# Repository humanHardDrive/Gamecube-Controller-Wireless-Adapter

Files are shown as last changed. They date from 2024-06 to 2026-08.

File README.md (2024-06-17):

# GameCube Wireless Controller Hub
The GameCube Wireless Controller hub allows 4 GameCube controllers to be made wireless to any GameCube controller interface. The hub functions in two halves, one to connect to the controllers, and one to connect to the console. Both halves are based on the RP2040 microcontroller and the NRF24l01 transceiver and share the same source code.

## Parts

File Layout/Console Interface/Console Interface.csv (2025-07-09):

# | Reference | Qty | Value | Footprint | DNP
1 | C1, C7, C9 | 3 | 2u2 | Capacitor_SMD:C_0603_1608Metric
2 | C2, C5, C6, C8, C10, C11, C12, C13, C14 | 9 | 100n | Capacitor_SMD:C_0603_1608Metric
3 | C3, C4 | 2 | 15p | Capacitor_SMD:C_0603_1608Metric
4 | C15, C16, C19, C20 | 4 | C | Capacitor_SMD:C_0603_1608Metric
5 | D1, D4, D5, D6, D7, D8, D9 | 7 | LED | LED_SMD:LED_0603_1608Metric
6 | D2, D3 | 2 | D_Schottky | Diode_SMD:D_0805_2012Metric
7 | H1, H2, H3, H4 | 4 | MountingHole | MountingHole:MountingHole_2.2mm_M2
8 | J1 | 1 | USB_C_Receptacle_USB2.0 | Connector_USB:USB_C_Receptacle_GCT_USB4105-xx-A_16P_TopMnt_Horizontal
9 | J2, J3, J4, J6 | 4 | Conn_01x04_Socket | Connector_Molex:Molex_Pico-EZmate_78171-0005_1x05-1MP_P1.20mm_Vertical
10 | Q1 | 1 | AO3401A | Package_TO_SOT_SMD:SOT-23
11 | R1 | 1 | 1K | Resistor_SMD:R_0603_1608Metric
12 | R2, R3 | 2 | 27 | Resistor_SMD:R_0603_1608Metric
13 | R4, R5 | 2 | 5K1 | Resistor_SMD:R_0603_1608Metric
14 | R6, R8, R11, R12, R13, R16, R17 | 7 | 100 | Resistor_SMD:R_0603_1608Metric
15 | R7 | 1 | 10K | Resistor_SMD:R_0603_1608Metric
16 | SW1 | 1 | SW_BOOT | Button_Switch_SMD:SW_SPST_TL3342
17 | SW3 | 1 | SW_PAIR | Button_Switch_SMD:SW_SPST_B3U-3000P
18 | U1 | 1 | W25Q32JVSS | Package_SO:SOIC-8_5.23x5.23mm_P1.27mm
19 | U2 | 1 | RP2040 | Package_DFN_QFN:QFN-56-1EP_7x7mm_P0.4mm_EP3.2x3.2mm
20 | U3 | 1 | ~ | GTS24:GTS24-SMD
21 | U4, U5 | 2 | MIC5504-3.3YM5 | Package_TO_SOT_SMD:SOT-23-5
22 | Y1 | 1 | Crystal_GND24 | Crystal:Crystal_SMD_Abracon_ABM8G-4Pin_3.2x2.5mm

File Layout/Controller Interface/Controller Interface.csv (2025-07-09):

# | Reference | Qty | Value | Footprint | DNP
1 | C1, C12, C13, C14, C16, C17, C18, C19, C20 | 9 | 100n | Capacitor_SMD:C_0603_1608Metric
2 | C2, C11, C15 | 3 | 2u2 | Capacitor_SMD:C_0603_1608Metric
3 | C3, C4 | 2 | 15p | Capacitor_SMD:C_0603_1608Metric
4 | C5, C6 | 2 | 1u | Capacitor_SMD:C_0603_1608Metric
5 | C7, C8 | 2 | 1uF | Capacitor_SMD:C_0603_1608Metric
6 | C9 | 1 | 4.7uF | Capacitor_SMD:C_0603_1608Metric
7 | C10 | 1 | 22uF | Capacitor_SMD:C_0603_1608Metric
8 | D2, D3 | 2 | D_Schottky | Diode_SMD:D_0805_2012Metric
9 | J1 | 1 | USB_C_Receptacle_USB2.0 | Connector_USB:USB_C_Receptacle_GCT_USB4105-xx-A_16P_TopMnt_Horizontal
10 | J2 | 1 | Controller 2 | GameCube Controllers:Gamecube Controller Socket
11 | J3 | 1 | Controller 3 | GameCube Controllers:Gamecube Controller Socket
12 | J4 | 1 | Controller 4 | GameCube Controllers:Gamecube Controller Socket
13 | J5 | 1 | Conn_01x08_Socket | Connector_PinSocket_1.00mm:PinSocket_2x04_P1.00mm_Vertical_SMD
14 | J6 | 1 | Conn_01x02_Pin | Connector_JST:JST_PH_S2B-PH-SM4-TB_1x02-1MP_P2.00mm_Horizontal
15 | J7 | 1 | Controller 1 | GameCube Controllers:Gamecube Controller Socket
16 | L2 | 1 | 2.2uH | Inductor_SMD:L_0805_2012Metric
17 | Q1, Q2, Q3 | 3 | AO3401A | Package_TO_SOT_SMD:SOT-23
18 | R1, R2, R3, R13, R15 | 5 | 1K | Resistor_SMD:R_0603_1608Metric
19 | R5, R12 | 2 | 10k | Resistor_SMD:R_0603_1608Metric
20 | R6, R7 | 2 | 27 | Resistor_SMD:R_0603_1608Metric
21 | R8, R9 | 2 | 5K1 | Resistor_SMD:R_0603_1608Metric
22 | R10 | 1 | 2K | Resistor_SMD:R_0603_1608Metric
23 | R11 | 1 | 10K | Resistor_SMD:R_0603_1608Metric
24 | SW1 | 1 | PWR | Button_Switch_SMD:Panasonic_EVQPUK_EVQPUB
25 | SW3 | 1 | SW_PAIR | Button_Switch_SMD:Panasonic_EVQPUK_EVQPUB
26 | SW4 | 1 | SW_BOOT | Button_Switch_SMD:SW_SPST_TL3342
27 | U1 | 1 | W25Q32JVSS | Package_SO:SOIC-8_5.23x5.23mm_P1.27mm
28 | U2 | 1 | RP2040 | Package_DFN_QFN:QFN-56-1EP_7x7mm_P0.4mm_EP3.2x3.2mm
29 | U3 | 1 | ~ | GTS24:GTS24-SMD
30 | U4 | 1 | MCP73812T-420I-OT | Package_TO_SOT_SMD:SOT-23-5
31 | U5 | 1 | TPS613223ADBV | Package_TO_SOT_SMD:SOT-23-5
32 | U7 | 1 | MIC5504-3.3YM5 | Package_TO_SOT_SMD:SOT-23-5
33 | Y2 | 1 | Crystal_GND24 | Crystal:Crystal_SMD_Abracon_ABM8G-4Pin_3.2x2.5mm

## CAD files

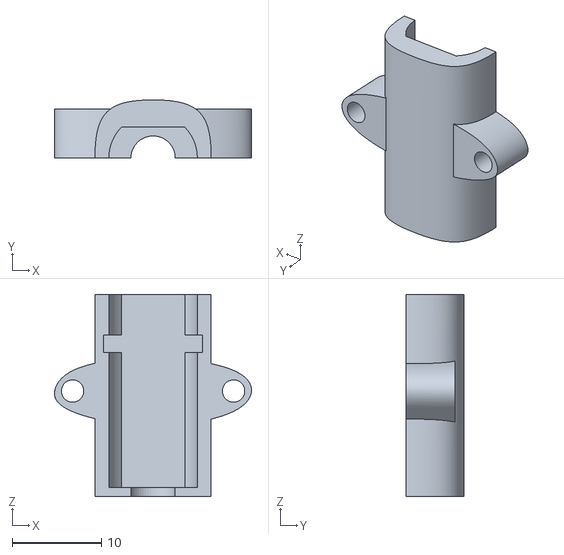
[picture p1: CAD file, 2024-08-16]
Enclosures/Console Interface/Controller Plug Clamp Top.stl
22.0 x 6.50 x 22.6

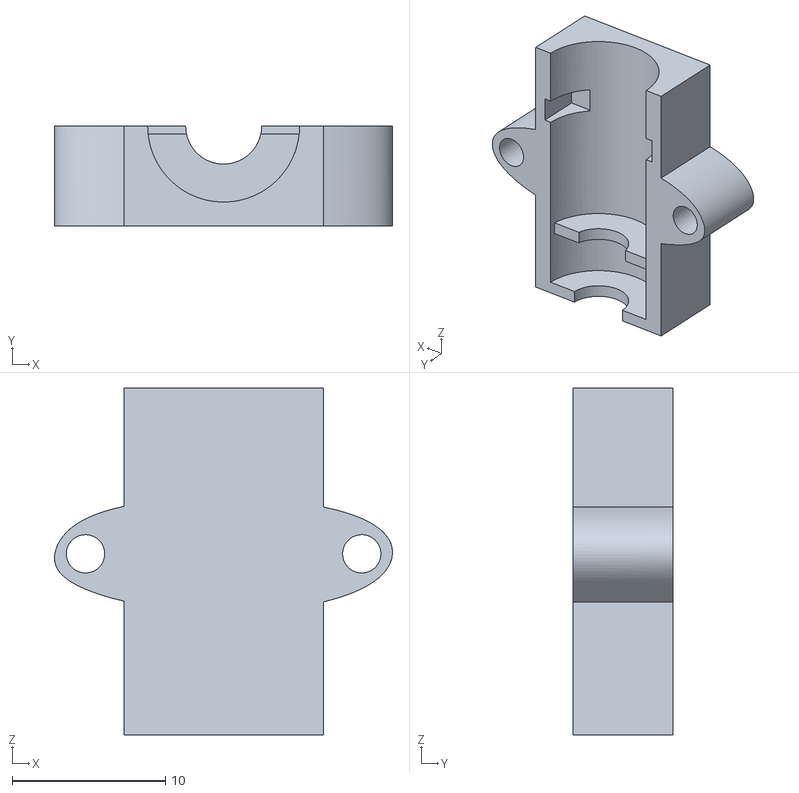
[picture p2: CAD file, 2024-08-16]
Enclosures/Console Interface/Controller Plug Clamp Bottom.stl
22.0 x 6.50 x 22.6

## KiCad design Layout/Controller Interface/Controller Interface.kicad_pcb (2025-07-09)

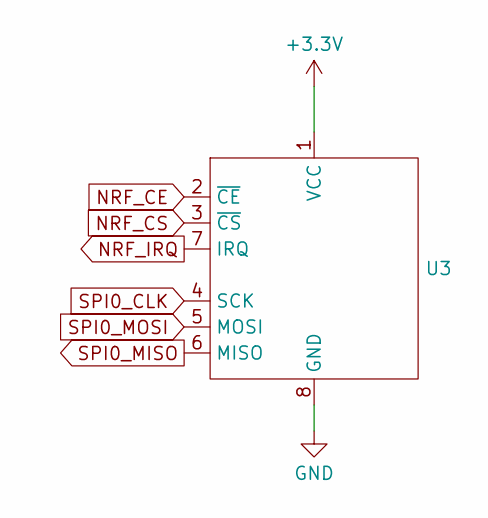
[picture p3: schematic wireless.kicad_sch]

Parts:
U3: GTS24-SMD

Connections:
+3.3V: U3.1 (VCC); also elsewhere on the board
GND: U3.8 (GND); also elsewhere on the board
NRF_CE: U3.2 (~CE); also elsewhere on the board
NRF_CS: U3.3 (~CS); also elsewhere on the board
NRF_IRQ: U3.7 (IRQ); also elsewhere on the board
SPI0_CLK: U3.4 (SCK); also elsewhere on the board
SPI0_MISO: U3.6 (MISO); also elsewhere on the board
SPI0_MOSI: U3.5 (MOSI); also elsewhere on the board

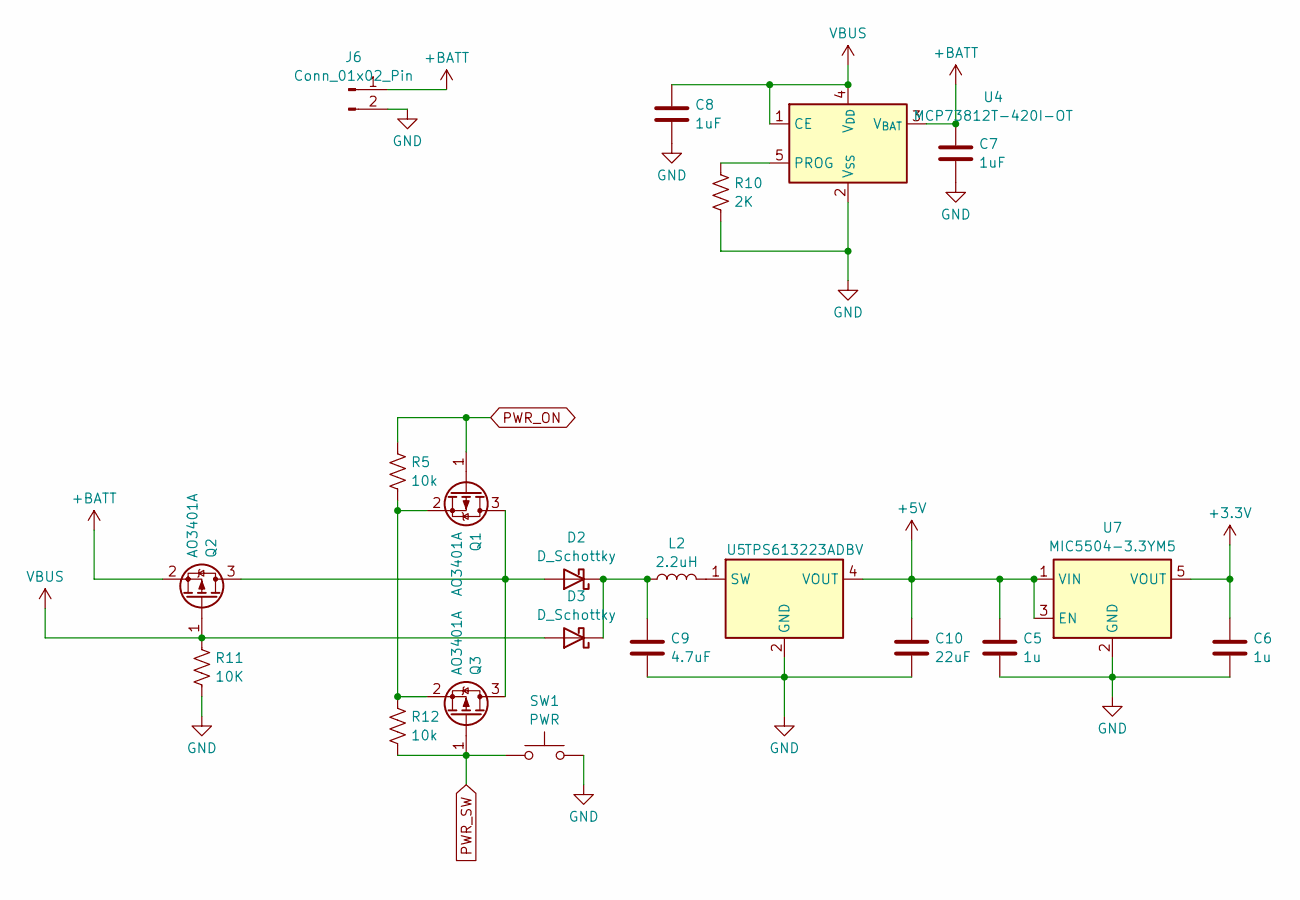
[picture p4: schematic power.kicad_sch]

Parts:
C5, C6: 1u; C_0603_1608Metric
C7, C8: 1uF; C_0603_1608Metric
C9: 4.7uF; C_0603_1608Metric
C10: 22uF; C_0603_1608Metric
D2, D3: D_Schottky; D_0805_2012Metric
J6: Conn_01x02_Pin; JST_PH_S2B-PH-SM4-TB_1x02-1MP_P2.00mm_Horizontal
L2: 2.2uH; L_0805_2012Metric
Q1, Q2, Q3: AO3401A; SOT-23
R5, R12: 10k; R_0603_1608Metric
R10: 2K; R_0603_1608Metric
R11: 10K; R_0603_1608Metric
SW1: PWR; Panasonic_EVQPUK_EVQPUB
U4: MCP73812T-420I-OT; SOT-23-5
U5: TPS613223ADBV; SOT-23-5
U7: MIC5504-3.3YM5; SOT-23-5

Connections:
+3.3V: C6.1, U7.5 (VOUT); also elsewhere on the board
+5V: C5.1, C10.1, U5.4 (VOUT), U7.1 (VIN), U7.3 (EN); also elsewhere on the board
+BATT: C7.1, J6.1, Q2.2 (S), U4.3 (V_{BAT})
GND: C5.2, C6.2, C7.2, C8.2, C9.2, C10.2, J6.2, R10.2, R11.1, SW1.2, U4.2 (V_{SS}), U5.2 (GND), U7.2 (GND); also elsewhere on the board
unnamed: D2.2 (A), Q1.3 (D), Q2.3 (D), Q3.3 (D)
unnamed: C9.1, D2.1 (K), D3.1 (K), L2.1
unnamed: Q1.2 (S), Q3.2 (S), R5.2, R12.1
unnamed: R10.1, U4.5 (PROG)
unnamed: L2.2, U5.1 (SW)
PWR_ON: Q1.1 (G), R5.1; also elsewhere on the board
PWR_SW: Q3.1 (G), R12.2, SW1.1; also elsewhere on the board
VBUS: C8.1, D3.2 (A), Q2.1 (G), R11.2, U4.1 (CE), U4.4 (V_{DD}); also elsewhere on the board

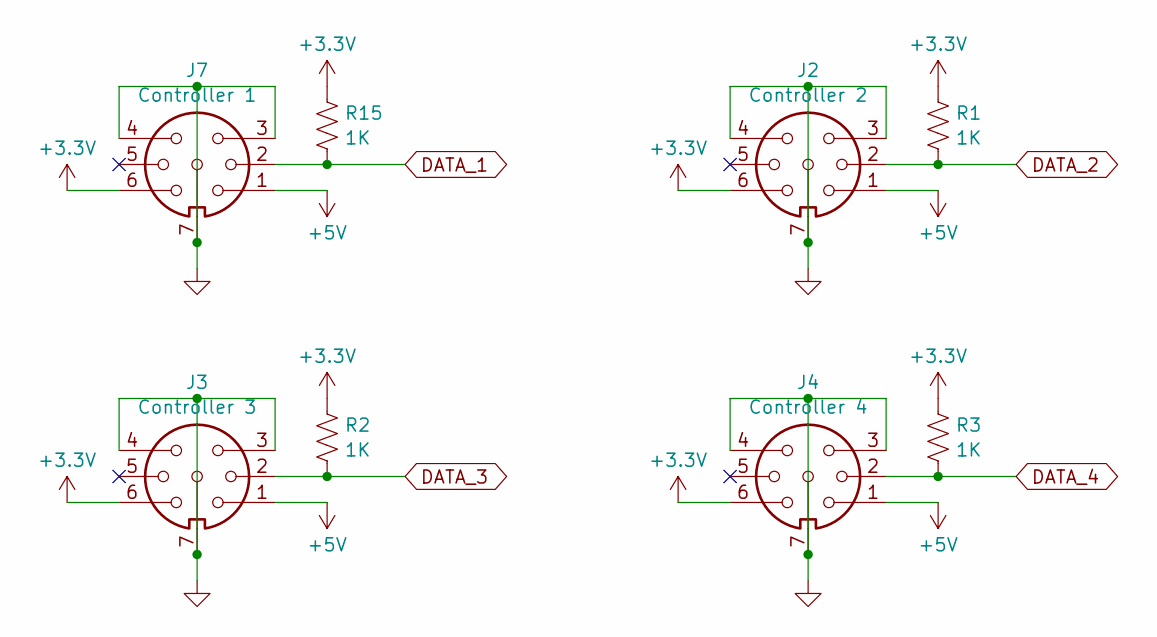
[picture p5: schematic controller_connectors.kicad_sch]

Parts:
J2: Controller 2; Gamecube Controller Socket
J3: Controller 3; Gamecube Controller Socket
J4: Controller 4; Gamecube Controller Socket
J7: Controller 1; Gamecube Controller Socket
R1, R2, R3, R15: 1K; R_0603_1608Metric

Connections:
+3.3V: J2.6, J3.6, J4.6, J7.6, R1.1, R2.1, R3.1, R15.1; also elsewhere on the board
+5V: J2.1, J3.1, J4.1, J7.1; also elsewhere on the board
DATA_1: J7.2, R15.2; also elsewhere on the board
DATA_2: J2.2, R1.2; also elsewhere on the board
DATA_3: J3.2, R2.2; also elsewhere on the board
DATA_4: J4.2, R3.2; also elsewhere on the board
GND: J2.3, J2.4, J2.7, J3.3, J3.4, J3.7, J4.3, J4.4, J4.7, J7.3, J7.4, J7.7; also elsewhere on the board

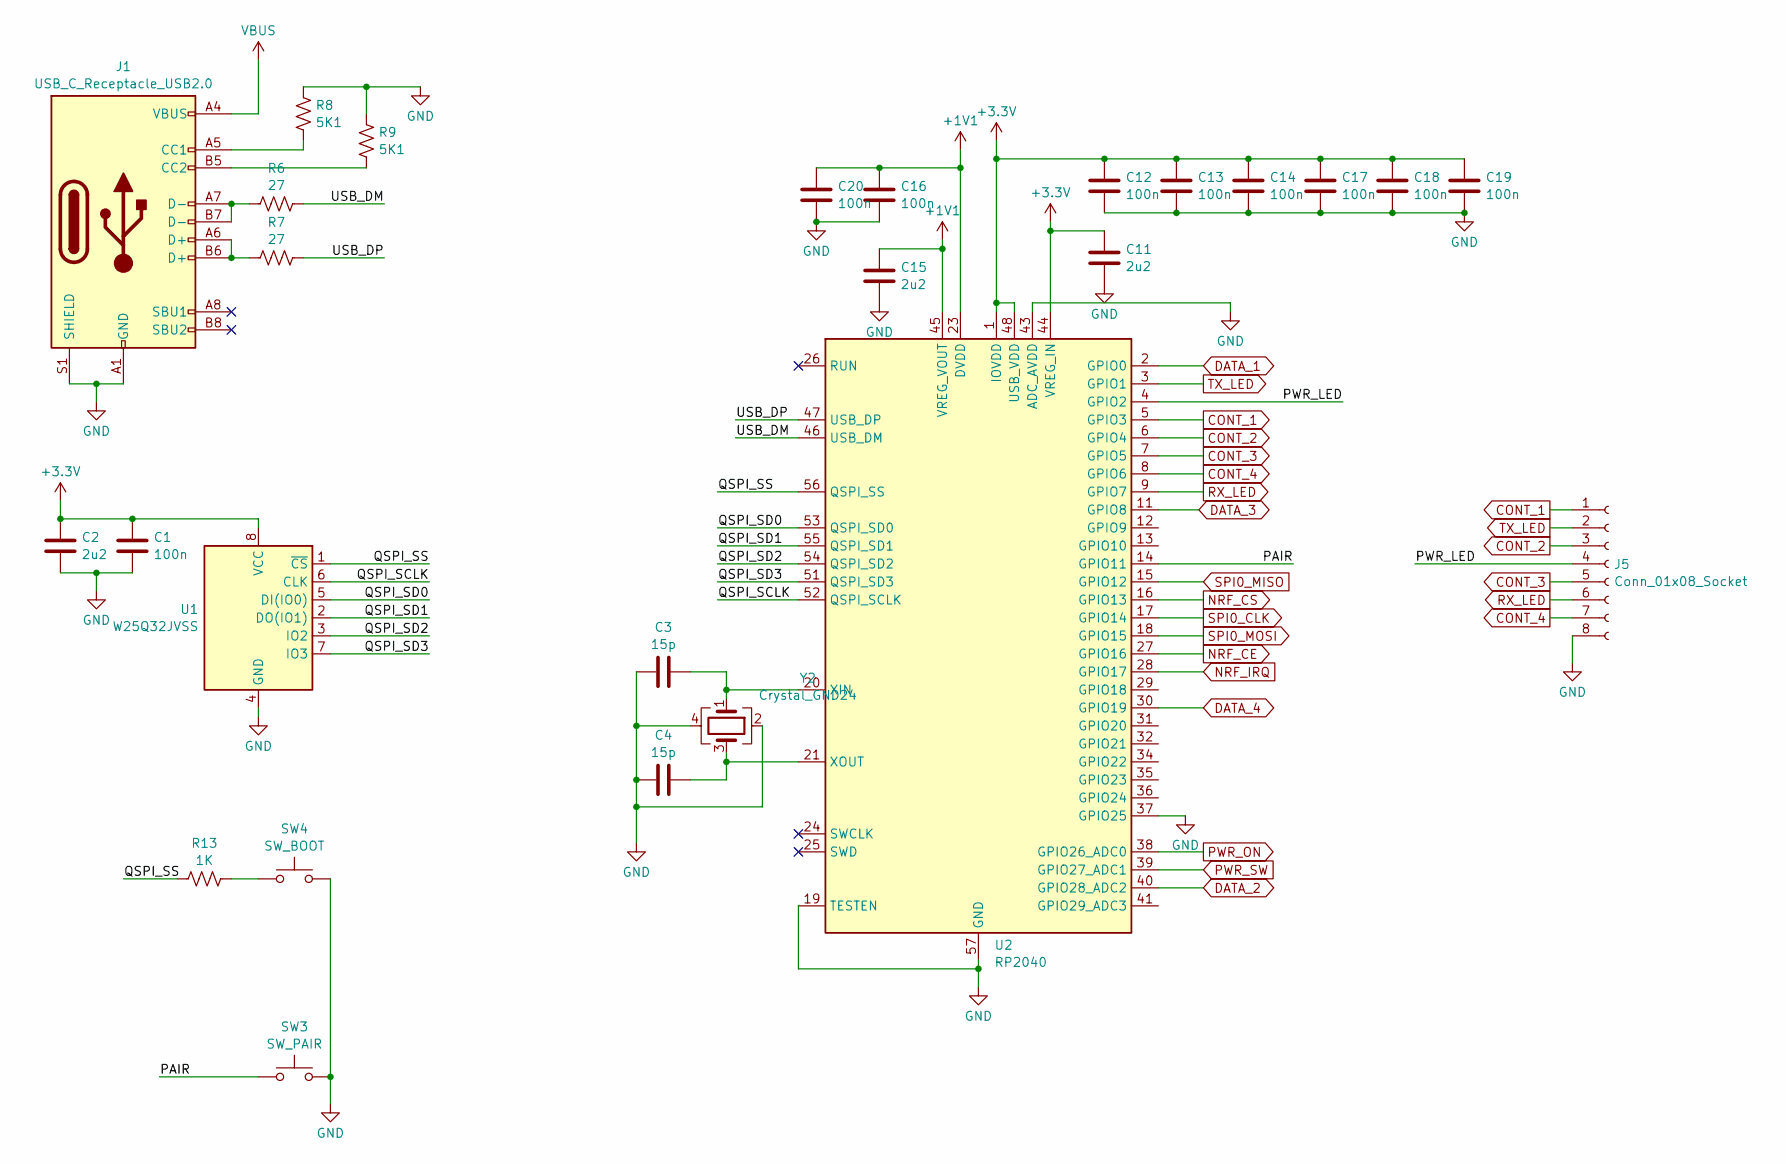
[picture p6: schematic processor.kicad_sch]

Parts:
C1, C12, C13, C14, C16, C17, C18, C19, C20: 100n; C_0603_1608Metric
C2, C11, C15: 2u2; C_0603_1608Metric
C3, C4: 15p; C_0603_1608Metric
J1: USB_C_Receptacle_USB2.0; USB_C_Receptacle_GCT_USB4105-xx-A_16P_TopMnt_Horizontal
J5: Conn_01x08_Socket; PinSocket_2x04_P1.00mm_Vertical_SMD
R6, R7: 27; R_0603_1608Metric
R8, R9: 5K1; R_0603_1608Metric
R13: 1K; R_0603_1608Metric
SW3: SW_PAIR; Panasonic_EVQPUK_EVQPUB
SW4: SW_BOOT; SW_SPST_TL3342
U1: W25Q32JVSS; SOIC-8_5.23x5.23mm_P1.27mm
U2: RP2040; QFN-56-1EP_7x7mm_P0.4mm_EP3.2x3.2mm
Y2: Crystal_GND24; Crystal_SMD_Abracon_ABM8G-4Pin_3.2x2.5mm

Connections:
+1V1: C15.1, C16.1, C20.1, U2.23 (DVDD), U2.45 (VREG_VOUT), U2.50 (DVDD)
+3.3V: C1.1, C2.1, C11.1, C12.1, C13.1, C14.1, C17.1, C18.1, C19.1, U1.8 (VCC), U2.1 (IOVDD), U2.10 (IOVDD), U2.22 (IOVDD), U2.33 (IOVDD), U2.42 (IOVDD), U2.44 (VREG_IN), U2.48 (USB_VDD), U2.49 (IOVDD); also elsewhere on the board
/Processor/PAIR: SW3.1, U2.14 (GPIO11)
/Processor/PWR_LED: J5.4, U2.4 (GPIO2)
/Processor/QSPI_SCLK: U1.6 (CLK), U2.52 (QSPI_SCLK)
/Processor/QSPI_SD0: U1.5 (DI(IO0)), U2.53 (QSPI_SD0)
/Processor/QSPI_SD1: U1.2 (DO(IO1)), U2.55 (QSPI_SD1)
/Processor/QSPI_SD2: U1.3 (IO2), U2.54 (QSPI_SD2)
/Processor/QSPI_SD3: U1.7 (IO3), U2.51 (QSPI_SD3)
/Processor/QSPI_SS: R13.1, U1.1 (~CS), U2.56 (QSPI_SS)
/Processor/USB_DM: R6.2, U2.46 (USB_DM)
/Processor/USB_DP: R7.2, U2.47 (USB_DP)
CONT_1: J5.1, U2.5 (GPIO3)
CONT_2: J5.3, U2.6 (GPIO4)
CONT_3: J5.5, U2.7 (GPIO5)
CONT_4: J5.7, U2.8 (GPIO6)
DATA_1: U2.2 (GPIO0); also elsewhere on the board
DATA_2: U2.40 (GPIO28_ADC2); also elsewhere on the board
DATA_3: U2.11 (GPIO8); also elsewhere on the board
DATA_4: U2.30 (GPIO19); also elsewhere on the board
GND: C1.2, C2.2, C3.2, C4.1, C11.2, C12.2, C13.2, C14.2, C15.2, C16.2, C17.2, C18.2, C19.2, C20.2, J1.A1 (GND), J1.A12 (GND), J1.B1 (GND), J1.B12 (GND), J1.S1 (SHIELD), J5.8, R8.2, R9.2, SW3.2, SW4.2, U1.4 (GND), U2.19 (TESTEN), U2.37 (GPIO25), U2.43 (ADC_AVDD), U2.57 (GND), Y2.2, Y2.4; also elsewhere on the board
NRF_CE: U2.27 (GPIO16); also elsewhere on the board
NRF_CS: U2.16 (GPIO13); also elsewhere on the board
NRF_IRQ: U2.28 (GPIO17); also elsewhere on the board
unnamed: J1.A5 (CC1), R8.1
unnamed: J1.B5 (CC2), R9.1
unnamed: J1.A6 (D+), J1.B6 (D+), R7.1
unnamed: J1.A7 (D-), J1.B7 (D-), R6.1
unnamed: R13.2, SW4.1
unnamed: C3.1, U2.20 (XIN), Y2.1
unnamed: C4.2, U2.21 (XOUT), Y2.3
PWR_ON: U2.38 (GPIO26_ADC0); also elsewhere on the board
PWR_SW: U2.39 (GPIO27_ADC1); also elsewhere on the board
RX_LED: J5.6, U2.9 (GPIO7)
SPI0_CLK: U2.17 (GPIO14); also elsewhere on the board
SPI0_MISO: U2.15 (GPIO12); also elsewhere on the board
SPI0_MOSI: U2.18 (GPIO15); also elsewhere on the board
TX_LED: J5.2, U2.3 (GPIO1)
VBUS: J1.A4 (VBUS), J1.A9 (VBUS), J1.B4 (VBUS), J1.B9 (VBUS); also elsewhere on the board

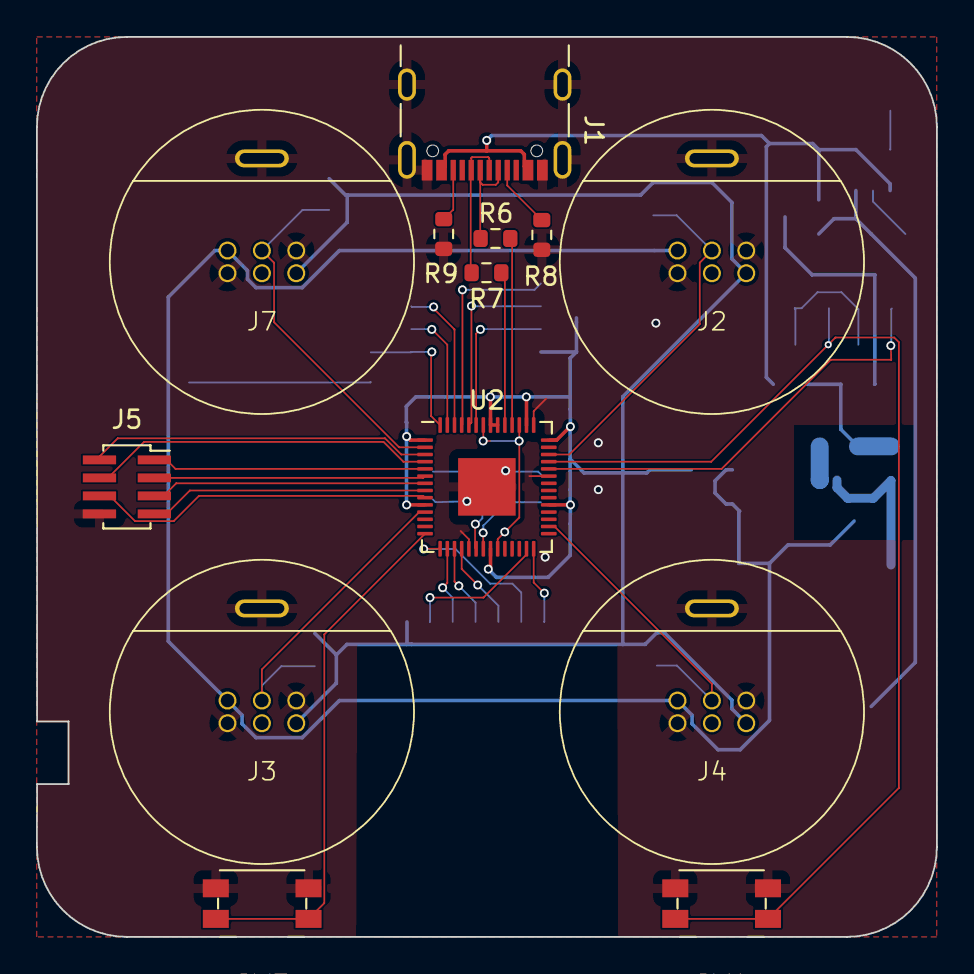
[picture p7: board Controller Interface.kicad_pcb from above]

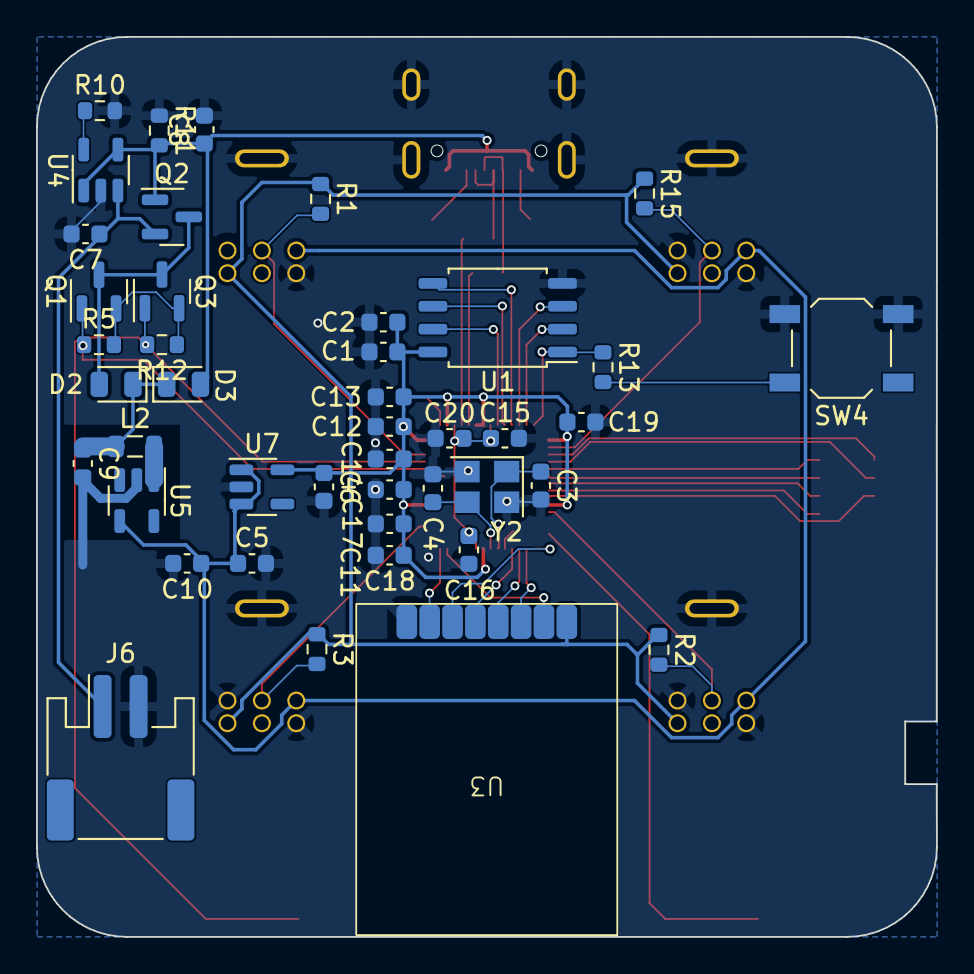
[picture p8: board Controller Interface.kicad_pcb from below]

Board: 2 copper layers, 50.0 x 50.0 mm, 56 parts (43 on the bottom side), 46 nets.

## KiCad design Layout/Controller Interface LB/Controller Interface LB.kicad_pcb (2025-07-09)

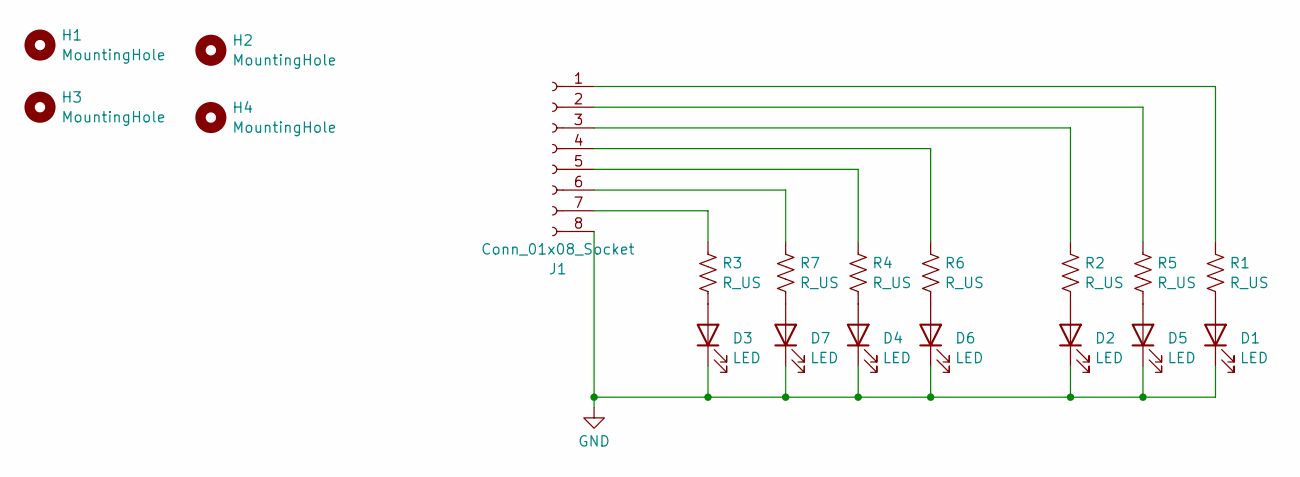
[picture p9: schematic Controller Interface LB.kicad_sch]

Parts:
D1, D2, D3, D4, D5, D6, D7: LED; LED_0603_1608Metric
H1, H2, H3, H4: MountingHole; MountingHole_2.2mm_M2
J1: Conn_01x08_Socket; PinSocket_2x04_P1.00mm_Vertical_SMD
R1, R2, R3, R4, R5, R6, R7: R_US; R_0603_1608Metric

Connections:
GND: D1.1 (K), D2.1 (K), D3.1 (K), D4.1 (K), D5.1 (K), D6.1 (K), D7.1 (K), J1.8
unnamed: D1.2 (A), R1.2
unnamed: D2.2 (A), R2.2
unnamed: D3.2 (A), R3.2
unnamed: D4.2 (A), R4.2
unnamed: D5.2 (A), R5.2
unnamed: D6.2 (A), R6.2
unnamed: D7.2 (A), R7.2
unnamed: J1.1, R1.1
unnamed: J1.2, R5.1
unnamed: J1.3, R2.1
unnamed: J1.4, R6.1
unnamed: J1.5, R4.1
unnamed: J1.6, R7.1
unnamed: J1.7, R3.1

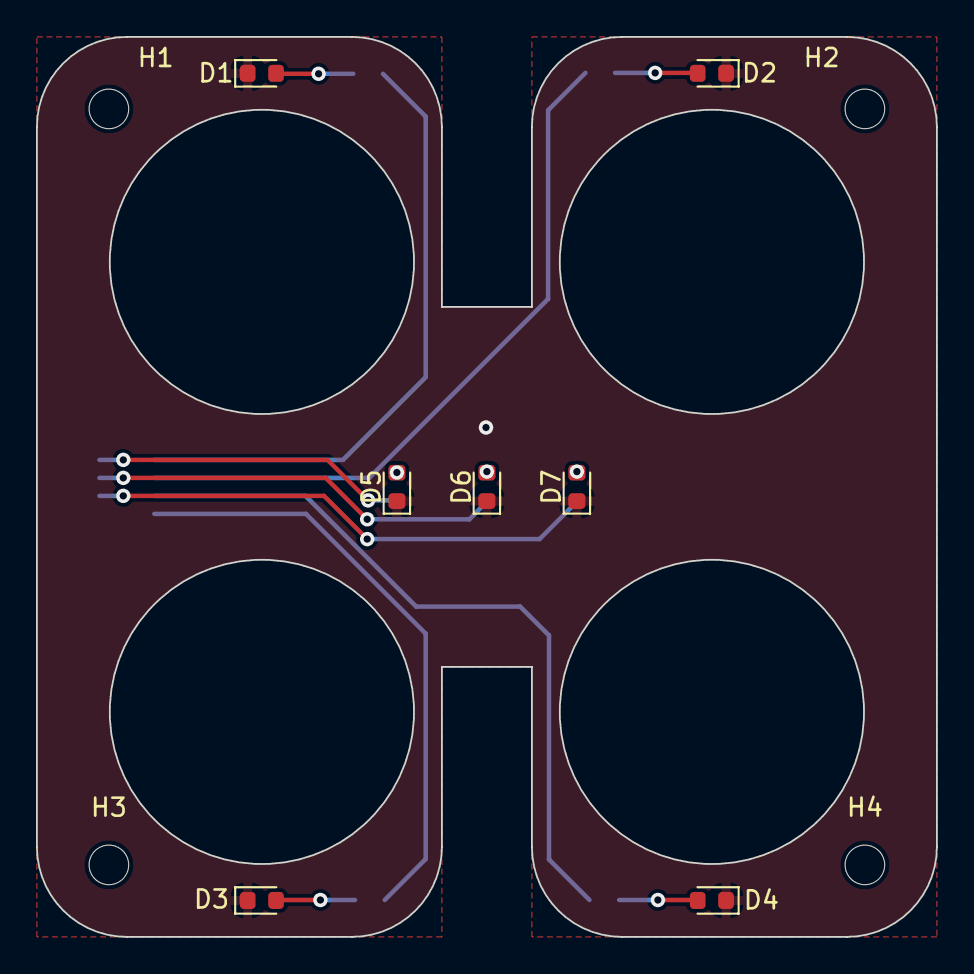
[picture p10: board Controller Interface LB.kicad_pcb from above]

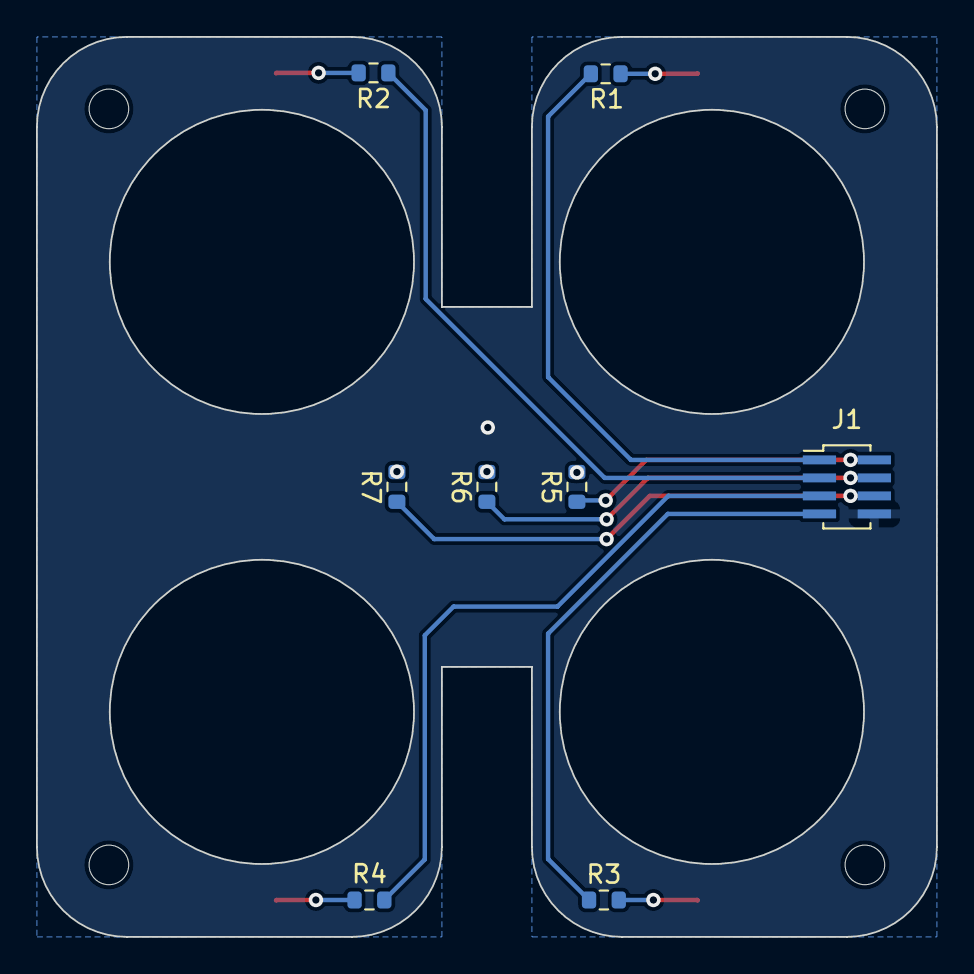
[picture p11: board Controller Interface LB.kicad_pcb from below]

Board: 2 copper layers, 50.0 x 50.0 mm, 19 parts (8 on the bottom side), 15 nets.

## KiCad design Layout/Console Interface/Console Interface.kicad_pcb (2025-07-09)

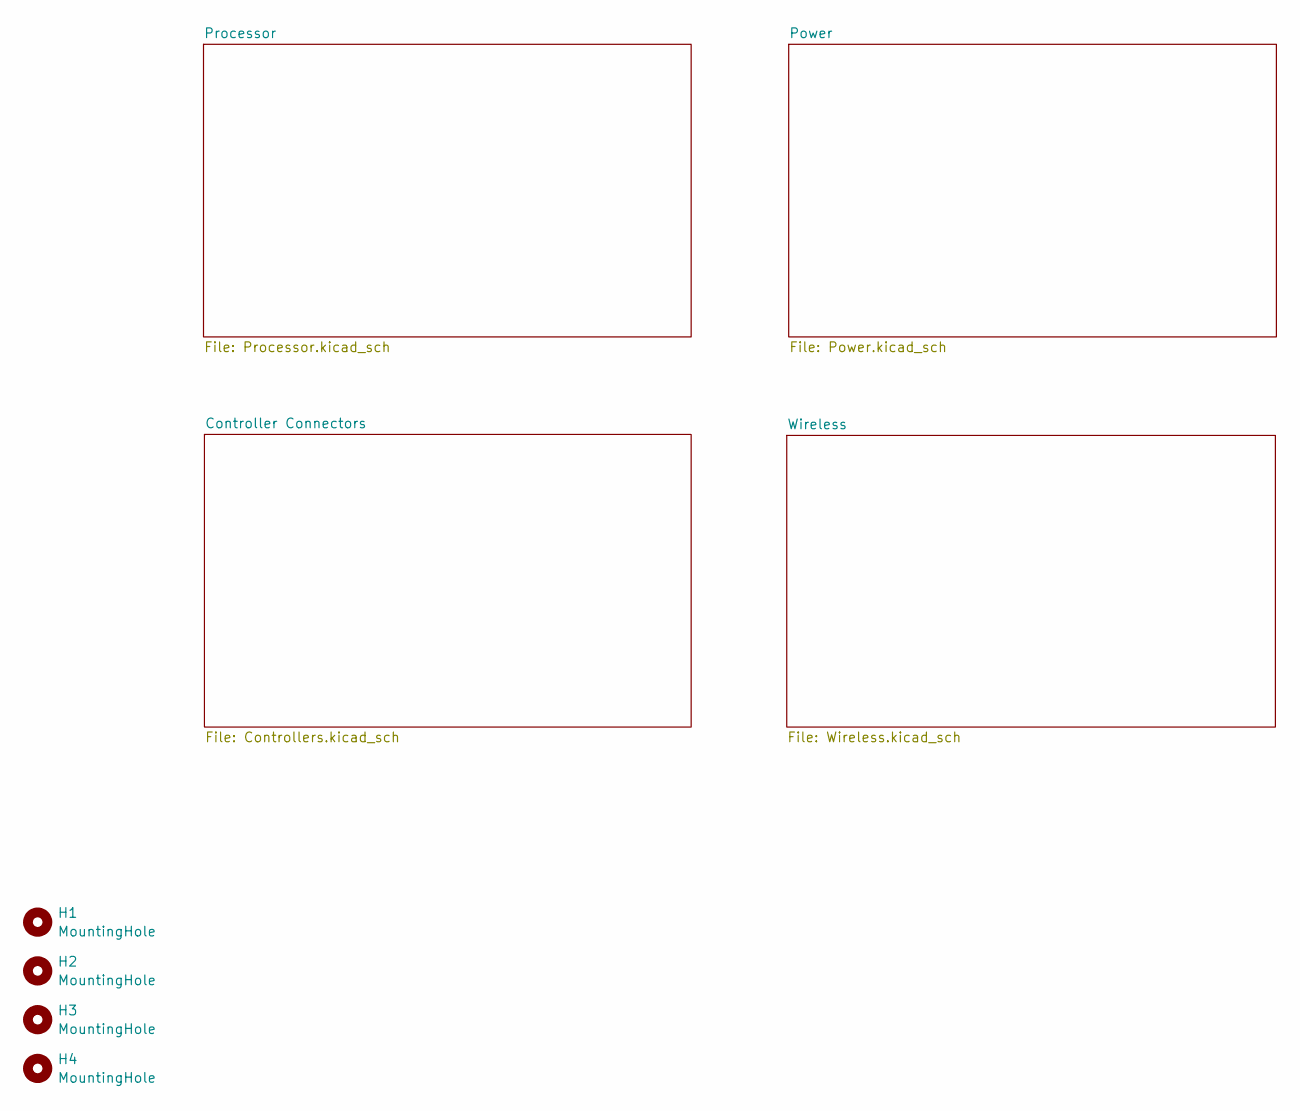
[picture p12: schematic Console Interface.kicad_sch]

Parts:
H1, H2, H3, H4: MountingHole; MountingHole_2.2mm_M2

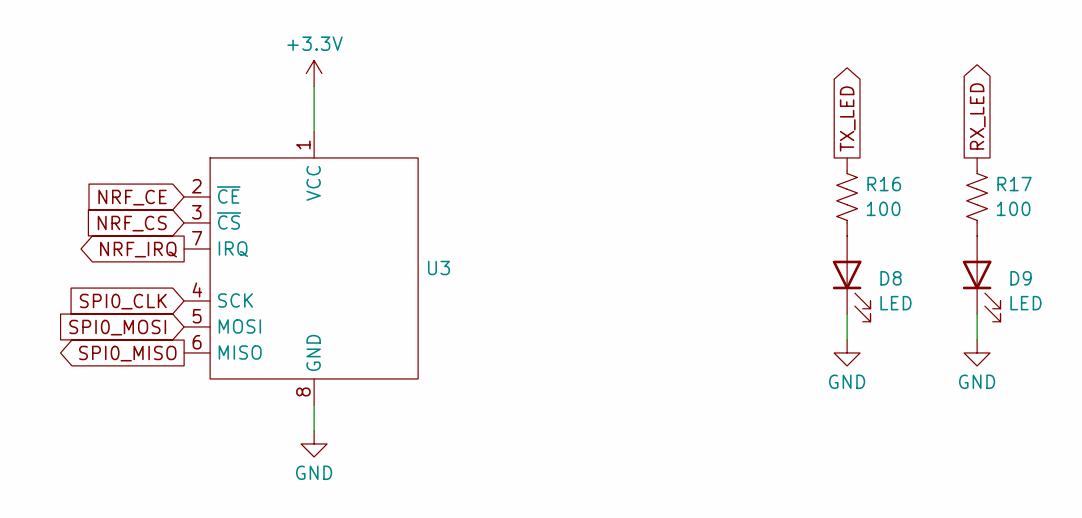
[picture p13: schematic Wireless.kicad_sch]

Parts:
D8, D9: LED; LED_0603_1608Metric
R16, R17: 100; R_0603_1608Metric
U3: GTS24-SMD

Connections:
+3.3V: U3.1 (VCC); also elsewhere on the board
GND: D8.1 (K), D9.1 (K), U3.8 (GND); also elsewhere on the board
NRF_CE: U3.2 (~CE); also elsewhere on the board
NRF_CS: U3.3 (~CS); also elsewhere on the board
NRF_IRQ: U3.7 (IRQ)
unnamed: D8.2 (A), R16.2
unnamed: D9.2 (A), R17.2
RX_LED: R17.1; also elsewhere on the board
SPI0_CLK: U3.4 (SCK); also elsewhere on the board
SPI0_MISO: U3.6 (MISO); also elsewhere on the board
SPI0_MOSI: U3.5 (MOSI); also elsewhere on the board
TX_LED: R16.1; also elsewhere on the board

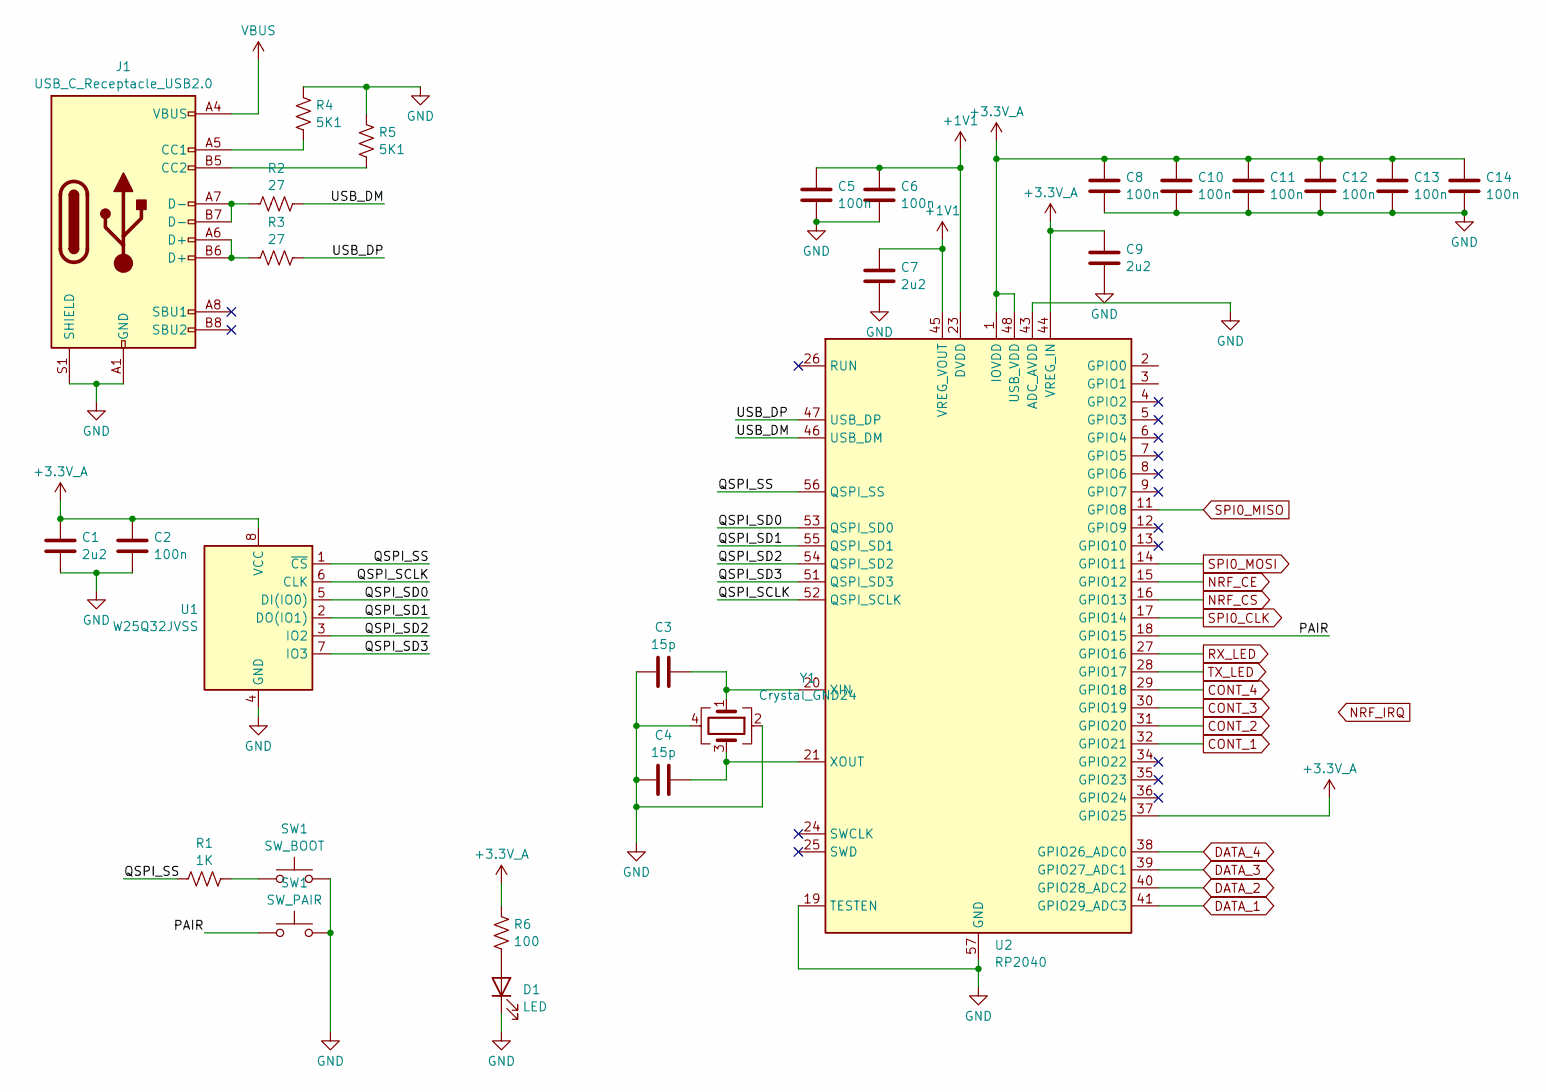
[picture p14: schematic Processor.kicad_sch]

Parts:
C1, C7, C9: 2u2; C_0603_1608Metric
C2, C5, C6, C8, C10, C11, C12, C13, C14: 100n; C_0603_1608Metric
C3, C4: 15p; C_0603_1608Metric
D1: LED; LED_0603_1608Metric
J1: USB_C_Receptacle_USB2.0; USB_C_Receptacle_GCT_USB4105-xx-A_16P_TopMnt_Horizontal
R1: 1K; R_0603_1608Metric
R2, R3: 27; R_0603_1608Metric
R4, R5: 5K1; R_0603_1608Metric
R6: 100; R_0603_1608Metric
SW1: SW_BOOT; SW_SPST_TL3342
U1: W25Q32JVSS; SOIC-8_5.23x5.23mm_P1.27mm
U2: RP2040; QFN-56-1EP_7x7mm_P0.4mm_EP3.2x3.2mm
Y1: Crystal_GND24; Crystal_SMD_Abracon_ABM8G-4Pin_3.2x2.5mm

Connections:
+1V1: C5.1, C6.1, C7.1, U2.23 (DVDD), U2.45 (VREG_VOUT), U2.50 (DVDD)
+3.3V_A: C1.1, C2.1, C8.1, C9.1, C10.1, C11.1, C12.1, C13.1, C14.1, R6.1, U1.8 (VCC), U2.1 (IOVDD), U2.10 (IOVDD), U2.22 (IOVDD), U2.33 (IOVDD), U2.37 (GPIO25), U2.42 (IOVDD), U2.44 (VREG_IN), U2.48 (USB_VDD), U2.49 (IOVDD); also elsewhere on the board
/Processor/QSPI_SCLK: U1.6 (CLK), U2.52 (QSPI_SCLK)
/Processor/QSPI_SD0: U1.5 (DI(IO0)), U2.53 (QSPI_SD0)
/Processor/QSPI_SD1: U1.2 (DO(IO1)), U2.55 (QSPI_SD1)
/Processor/QSPI_SD2: U1.3 (IO2), U2.54 (QSPI_SD2)
/Processor/QSPI_SD3: U1.7 (IO3), U2.51 (QSPI_SD3)
/Processor/QSPI_SS: R1.1, U1.1 (~CS), U2.56 (QSPI_SS)
/Processor/USB_DM: R2.2, U2.46 (USB_DM)
/Processor/USB_DP: R3.2, U2.47 (USB_DP)
CONT_1: U2.32 (GPIO21); also elsewhere on the board
CONT_2: U2.31 (GPIO20); also elsewhere on the board
CONT_3: U2.30 (GPIO19); also elsewhere on the board
CONT_4: U2.29 (GPIO18); also elsewhere on the board
DATA_1: U2.41 (GPIO29_ADC3); also elsewhere on the board
DATA_2: U2.40 (GPIO28_ADC2); also elsewhere on the board
DATA_3: U2.39 (GPIO27_ADC1); also elsewhere on the board
DATA_4: U2.38 (GPIO26_ADC0); also elsewhere on the board
GND: C1.2, C2.2, C3.2, C4.1, C5.2, C6.2, C7.2, C8.2, C9.2, C10.2, C11.2, C12.2, C13.2, C14.2, D1.1 (K), J1.A1 (GND), J1.A12 (GND), J1.B1 (GND), J1.B12 (GND), J1.S1 (SHIELD), R4.2, R5.2, SW1.2, U1.4 (GND), U2.19 (TESTEN), U2.43 (ADC_AVDD), U2.57 (GND), Y1.2, Y1.4; also elsewhere on the board
NRF_CE: U2.15 (GPIO12); also elsewhere on the board
NRF_CS: U2.16 (GPIO13); also elsewhere on the board
unnamed: D1.2 (A), R6.2
unnamed: J1.A5 (CC1), R4.1
unnamed: J1.B5 (CC2), R5.1
unnamed: J1.A6 (D+), J1.B6 (D+), R3.1
unnamed: J1.A7 (D-), J1.B7 (D-), R2.1
unnamed: C3.1, U2.20 (XIN), Y1.1
unnamed: C4.2, U2.21 (XOUT), Y1.3
RX_LED: U2.27 (GPIO16); also elsewhere on the board
SPI0_CLK: U2.17 (GPIO14); also elsewhere on the board
SPI0_MISO: U2.11 (GPIO8); also elsewhere on the board
SPI0_MOSI: U2.14 (GPIO11); also elsewhere on the board
TX_LED: U2.28 (GPIO17); also elsewhere on the board
VBUS: J1.A4 (VBUS), J1.A9 (VBUS), J1.B4 (VBUS), J1.B9 (VBUS); also elsewhere on the board


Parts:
D4, D5, D6, D7: LED; LED_0603_1608Metric
J2, J3, J4, J6: Conn_01x04_Socket; JST_GH_BM05B-GHS-TBT_1x05-1MP_P1.25mm_Vertical
R8, R11, R12, R13: 100; R_0603_1608Metric

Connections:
+3.3V_A: J2.2, J3.2, J4.2, J6.2; also elsewhere on the board
+5V: J2.3, J3.3, J4.3, J6.3; also elsewhere on the board
CONT_1: R8.1; also elsewhere on the board
CONT_2: R11.1; also elsewhere on the board
CONT_3: R12.1; also elsewhere on the board
CONT_4: R13.1; also elsewhere on the board
DATA_1: J6.1; also elsewhere on the board
DATA_2: J2.1; also elsewhere on the board
DATA_3: J3.1; also elsewhere on the board
DATA_4: J4.1; also elsewhere on the board
GND: D4.1 (K), D5.1 (K), D6.1 (K), D7.1 (K), J2.4, J2.5, J3.4, J3.5, J4.4, J4.5, J6.4, J6.5; also elsewhere on the board
unnamed: D4.2 (A), R8.2
unnamed: D5.2 (A), R11.2
unnamed: D6.2 (A), R12.2
unnamed: D7.2 (A), R13.2


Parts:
C15, C16, C19, C20: C; C_0603_1608Metric
D2, D3: D_Schottky; D_0603_1608Metric
Q1: AO3401A; SOT-23
R7: 10K; R_0603_1608Metric
U4, U5: MIC5504-3.3YM5; SOT-23-5

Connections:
+3.3V: C20.1, U5.5 (VOUT); also elsewhere on the board
+3.3V_A: C16.1, U4.5 (VOUT); also elsewhere on the board
+5V: D3.2 (A), Q1.1 (G), R7.2; also elsewhere on the board
GND: C15.2, C16.2, C19.2, C20.2, R7.1, U4.2 (GND), U5.2 (GND); also elsewhere on the board
unnamed: C15.1, D2.2 (A), Q1.3 (D), U4.1 (VIN), U4.3 (EN)
unnamed: C19.1, D2.1 (K), D3.1 (K), U5.1 (VIN), U5.3 (EN)
VBUS: Q1.2 (S); also elsewhere on the board

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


Board: 2 copper layers, 130.5 x 75.2 mm, 58 parts (33 on the bottom side), 46 nets.

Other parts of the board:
SW3: SW_PAIR; Panasonic_EVQPUK_EVQPUB

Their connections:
GND: SW3.2; also elsewhere on the board

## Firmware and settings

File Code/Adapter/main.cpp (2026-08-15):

#include <stdint.h>
#include <stdio.h>

#include "pico/stdlib.h"
#include "pico/multicore.h"

#include "hardware/gpio.h"

#include "PinDefs.h"
#include "Utils.h"

#include "ControllerComm.h"
#include "WirelessComm.h"
#include "PowerManager.h"
#include "USBComm.h"

#include "bsp/board_api.h"
#include "tusb.h"
#include "usb_descriptors.h"

//Communication objects
ControllerComm controllerComm;
WirelessComm wirelessComm;
USBComm usbComm;
PowerManager powerManager;

#define CONTROLLER_COMM_OWNS_DATA   0
#define WIRELESS_COMM_OWNS_DATA     1

//Controller data signal
uint8_t nControllerDataOwner = CONTROLLER_COMM_OWNS_DATA;
//Controller data buffer
ControllerValues controllerBuffer[NUM_CONTROLLERS];
ConsoleValues consoleBuffer[NUM_CONTROLLERS];
//This buffer is ping-ponged between the controller and console interfaces using the switch above
//Each side takes turns updating, then consuming the data (controller produces, wireless consumes)
//The switch lets either side know when it is safe to do so
//The owner of the data is responsible for switching back when they're done

bool bTUDPollingActive = false;

bool timer_callback(repeating_timer_t* t)
{
    //If tud polling hasn't started yet, keep doing the task
    if(!bTUDPollingActive)
        tud_task();
    else //Otherwise, bail
        printf("Stopping timer callback\n");

    return bTUDPollingActive ? false : true;
}

/*
Function for the controller communication core
Communication between the controller/console is handled on a seperate processing core
to allow the main core to do wireless/USB communication
*/
void ControllerCommunicationCore()
{
    absolute_time_t lastControllerConnectedTime = get_absolute_time();

    //Signal back that the core has started
    multicore_fifo_push_blocking(0);
    printf("Controller core started\n");

    //Make sure this core isn't handling any USB interrupts
    irq_set_enabled(USBCTRL_IRQ, false);

    //Initialize the controller communication
    controllerComm.Init();

    while(1)
    {
        controllerComm.Background();

        //Ping-pong the ownership of the controller data between controller and wireless
        if(nControllerDataOwner == CONTROLLER_COMM_OWNS_DATA)
        {
            if(GetInterfaceType() == CONTROLLER_SIDE_INTERFACE)
            {
                controllerComm.GetControllerData(controllerBuffer);
                controllerComm.SetConsoleData(consoleBuffer);
            }
            else if(controllerComm.IsControllerInfoStale()) //Console side interface
            {
                controllerComm.GetConsoleData(consoleBuffer);
                controllerComm.SetControllerData(controllerBuffer);
            }

            nControllerDataOwner = WIRELESS_COMM_OWNS_DATA;
        }

        if(GetInterfaceType() == CONTROLLER_SIDE_INTERFACE)
        {
            if(!controllerComm.AnyControllerConnected() &&
                (absolute_time_diff_us(lastControllerConnectedTime, get_absolute_time()) > 5000))
            {
                lastControllerConnectedTime = get_absolute_time();
            }
            else if(controllerComm.AnyControllerConnected())
            {
                lastControllerConnectedTime = get_absolute_time();
            }
        }
    }
}

void WirelessCommunicationCore()
{
    bool bDataReceived = false;
    uint8_t nMissedMsgs = 0;
    absolute_time_t lastMsgTXTime = get_absolute_time();
    absolute_time_t lastMsgRXTime = get_absolute_time();

    printf("Wireless core started\n");

    //Init the wireless communication
    bool bInitSuccess = wirelessComm.Init();

    while(1)
    {
        wirelessComm.Background();

        //Ping-pong the ownership of the controller data between controller and wireless
        if(nControllerDataOwner == WIRELESS_COMM_OWNS_DATA)
        {
            if(bInitSuccess)
            {
                uint8_t rxBuf[MAX_PAYLOAD_SIZE];
                uint8_t nBytesRead = 0;

                if(nBytesRead = wirelessComm.Read(rxBuf, MAX_PAYLOAD_SIZE))
                {
                    bDataReceived = true;
                    lastMsgRXTime = get_absolute_time();
                }

                if(GetInterfaceType() == CONSOLE_SIDE_INTERFACE)
                {
                    uint deltaTime = absolute_time_diff_us(lastMsgTXTime, get_absolute_time());
                    
                    //Either a response has been recieved from the controller side interface
                    //Or more than 1 millisecond has elapsed
                    if(deltaTime > 1000)
                    {
                        lastMsgTXTime = get_absolute_time();

                        if(bDataReceived)
                        {
                            //Copy over the controller data from the controller side interface
                            memcpy(controllerBuffer, rxBuf, MAX_PAYLOAD_SIZE);
                            nMissedMsgs = 0;
                        }
                        else
                        {
                            if(nMissedMsgs < 3)
                                nMissedMsgs++;

                            if(nMissedMsgs >= 3)
                            {
                                memset(controllerBuffer, 0, sizeof(controllerBuffer));
                            }
                        }

                        //Write console side controller data
                        wirelessComm.Write(consoleBuffer, sizeof(consoleBuffer));
                        //Clear the received flag to wait to transmit again
                        bDataReceived = false;
                    }
                }
                else //Controller side interface
                {
                    //Check if there has been a message from the console side interface
                    if(bDataReceived)
                    {
                        //Copy over the controller data from the controller side interface
                        memcpy(consoleBuffer, rxBuf, sizeof(consoleBuffer));
                        //Write controller side controller data
                        wirelessComm.Write(controllerBuffer, sizeof(controllerBuffer));
                        //Clear the received flag to wait to transmit again
                        bDataReceived = false;
                    }
                }
            }

            for(uint8_t i = 0; i < NUM_CONTROLLERS; i++)
            {   
                hid_gamepad_report_t report;
                uint8_t hatVal = 0;

                report.x = controllerBuffer[i].JoyX;
                report.y = controllerBuffer[i].JoyY;

                report.z = controllerBuffer[i].CX;
                report.rz = controllerBuffer[i].CY;

                report.rx = controllerBuffer[i].LVal;
                report.ry = controllerBuffer[i].RVal;

                report.hat = (controllerBuffer[i].DUp << GAMEPAD_HAT_UP) | (controllerBuffer[i].DDown << GAMEPAD_HAT_DOWN) |
                                        (controllerBuffer[i].DLeft << GAMEPAD_HAT_LEFT) | (controllerBuffer[i].DRight << GAMEPAD_HAT_RIGHT);
                
                usbComm.SetReport(i + REPORT_ID_GAMEPAD_1, &report);
            }

            //Switch back to the controller comm owning data
            nControllerDataOwner = CONTROLLER_COMM_OWNS_DATA;
        }

        //Set this flag to stop the timer from handling usb updates
        bTUDPollingActive = true;
        //Update tiny usb
        tud_task();
        //Send out any reports
        usbComm.Background();
    }
}

int main()
{
    repeating_timer_t timer;

    //Initialize tiny usb at the start to do print statements
    //TinyUSB and the pico sdk usb CDC can't be used at the same time
    board_init();
    const tusb_rhport_init_t rh_init = {
        .role = TUSB_ROLE_DEVICE,
        .speed = TUD_OPT_HIGH_SPEED ? TUSB_SPEED_HIGH : TUSB_SPEED_FULL
    };
    tud_rhport_init(BOARD_TUD_RHPORT, &rh_init);
    board_init_after_tusb();

    //Pico sdk stdio does still work, but with the first CDC initialized through tinyUSB
    stdio_init_all();

    //WirelessCommunication core handles the TUD task
    //Until it's started, we can't do any serial prints
    //Start a repeating timer event to call the task every 10mS
    add_repeating_timer_ms(10, timer_callback, NULL, &timer);

    sleep_ms(1500);

    printf("Init pins\n");
    //Setup pins   
    gpio_init(GetDevicePinMap()->functionSelect);
    gpio_set_dir(GetDevicePinMap()->functionSelect, GPIO_IN);
    gpio_pull_up(GetDevicePinMap()->functionSelect);

    //Sleep to let the pins setup
    sleep_ms(150);

    //Detect device configuration
    if(!gpio_get(GetDevicePinMap()->functionSelect))
    {
        /*
        This is the controller side interface
        Poll for controller connection
        Poll for controller controllerValues
        Report controller controllerValues back to the console side interface
        */
       printf("Controller side interface\n");
       SetInterfaceType(CONTROLLER_SIDE_INTERFACE);
    }
    else
    {
        /*
        This is the console side interface
        Handle polling requests from the console
        Feed console data from controller side interface
        Communicate rumbe back to controller side interface
        */
       printf("Console side interface\n");
       SetInterfaceType(CONSOLE_SIDE_INTERFACE);
    }

    //Initialize the power manager to keep the board on
    powerManager.Init();

    powerManager.AddModuleToManage(&controllerComm);
    powerManager.AddModuleToManage(&wirelessComm);

    //Start the controller communication on the second core
    multicore_launch_core1(ControllerCommunicationCore);
    //Wait for the core to start
    uint32_t g = multicore_fifo_pop_blocking();

    //Start the wireless communication loop
    WirelessCommunicationCore();

    //Should never reach this
    return 0;
}

void tud_hid_report_complete_cb(uint8_t instance, uint8_t const* report, uint16_t len)
{
  (void)instance;
  (void)len;

  usbComm.SetLastSentReportID(report[0]);
}

uint16_t tud_hid_get_report_cb(uint8_t instance, uint8_t report_id, hid_report_type_t report_type, uint8_t* buffer, uint16_t reqlen)
{
  // TODO not Implemented
  (void) instance;
  (void) report_id;
  (void) report_type;
  (void) buffer;
  (void) reqlen;

  return 0;
}

void tud_hid_set_report_cb(uint8_t instance, uint8_t report_id, hid_report_type_t report_type, uint8_t const* buffer, uint16_t bufsize)
{
    (void) instance;
    (void) report_id;
    (void) report_type;
    (void) buffer;
    (void) bufsize;
}

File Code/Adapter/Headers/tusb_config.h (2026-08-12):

/*
 * The MIT License (MIT)
 *
 * Copyright (c) 2019 Ha Thach (tinyusb.org)
 *
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
 */

#ifndef _TUSB_CONFIG_H_
#define _TUSB_CONFIG_H_

#ifdef __cplusplus
 extern "C" {
#endif

//--------------------------------------------------------------------+
// Board Specific Configuration
//--------------------------------------------------------------------+

// RHPort number used for device can be defined by board.mk, default to port 0
#ifndef BOARD_TUD_RHPORT
#define BOARD_TUD_RHPORT      0
#endif

// RHPort max operational speed can defined by board.mk
#ifndef BOARD_TUD_MAX_SPEED
#define BOARD_TUD_MAX_SPEED   OPT_MODE_DEFAULT_SPEED
#endif

//--------------------------------------------------------------------
// COMMON CONFIGURATION
//--------------------------------------------------------------------

// defined by compiler flags for flexibility
#ifndef CFG_TUSB_MCU
#error CFG_TUSB_MCU must be defined
#endif

#ifndef CFG_TUSB_OS
#define CFG_TUSB_OS           OPT_OS_NONE
#endif

#ifndef CFG_TUSB_DEBUG
#define CFG_TUSB_DEBUG        0
#endif

// Enable Device stack
#define CFG_TUD_ENABLED       1

// Default is max speed that hardware controller could support with on-chip PHY
#define CFG_TUD_MAX_SPEED     BOARD_TUD_MAX_SPEED

/* USB DMA on some MCUs can only access a specific SRAM region with restriction on alignment.
 * Tinyusb use follows macros to declare transferring memory so that they can be put
 * into those specific section.
 * e.g
 * - CFG_TUSB_MEM SECTION : __attribute__ (( section(".usb_ram") ))
 * - CFG_TUSB_MEM_ALIGN   : __attribute__ ((aligned(4)))
 */
#ifndef CFG_TUSB_MEM_SECTION
#define CFG_TUSB_MEM_SECTION
#endif

#ifndef CFG_TUSB_MEM_ALIGN
#define CFG_TUSB_MEM_ALIGN          __attribute__ ((aligned(4)))
#endif

//--------------------------------------------------------------------
// DEVICE CONFIGURATION
//--------------------------------------------------------------------

#ifndef CFG_TUD_ENDPOINT0_SIZE
#define CFG_TUD_ENDPOINT0_SIZE    64
#endif

#define CFG_TUD_CDC_RX_BUFSIZE    64
#define CFG_TUD_CDC_TX_BUFSIZE    64

//------------- CLASS -------------//
#define CFG_TUD_HID               1
#define CFG_TUD_CDC               1
#define CFG_TUD_MSC               0
#define CFG_TUD_MIDI              0
#define CFG_TUD_VENDOR            0

// HID buffer size Should be sufficient to hold ID (if any) + Data
#define CFG_TUD_HID_EP_BUFSIZE    16

#ifdef __cplusplus
 }
#endif

#endif /* _TUSB_CONFIG_H_ */

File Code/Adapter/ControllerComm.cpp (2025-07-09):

#include "ControllerComm.h"

#include <string.h>
#include <stdio.h>

#include "pico/time.h"

#include "gcn_comm.pio.h"

#include "PinDefs.h"
#include "Utils.h"

ControllerComm::ControllerComm()
{
    auto_init_mutex(m_BackgroundLock);
    m_nStaleCount = 0;
}

void ControllerComm::SwitchModeTX(ControllerCommInfo* pController)
{
    pio_sm_exec_wait_blocking(pController->pio, pController->sm, gcn_comm_switch_tx(pController->offset));
}

void ControllerComm::SwitchModeRX(ControllerCommInfo* pController)
{
    pio_sm_exec_wait_blocking(pController->pio, pController->sm, gcn_comm_switch_rx(pController->offset));
}

/*
*/
bool ControllerComm::Init()
{
    //Generate the offset for the communication PIO program
    uint offset = pio_add_program(pio0, &gcn_comm_program);

    //Setup the controller data
    for(uint8_t i = 0; i < NUM_CONTROLLERS; i++)
    {
        //Clear out the controller values
        memset(&m_aControllerInfo[i].info.controllerValues, 0, sizeof(ControllerValues));

        //Clear out console values
        m_aControllerInfo[i].info.consoleValues.doRecal = false;
        m_aControllerInfo[i].info.consoleValues.doRumble = false;

        //Initialize the PIO references
        m_aControllerInfo[i].pio = pio0;
        m_aControllerInfo[i].sm = i;
        m_aControllerInfo[i].offset = offset;
        m_aControllerInfo[i].commPin = GetDevicePinMap()->controllerData[i];
        m_aControllerInfo[i].connectPin = GetDevicePinMap()->controllerStatus[i];

        //Initialize communication values
        m_aControllerInfo[i].info.isConnected = false;
        m_aControllerInfo[i].info.bIsStale = true;
        m_aControllerInfo[i].state = ControllerState::NOT_CONNECTED;
        m_aControllerInfo[i].LastPollTime = get_absolute_time();
        m_aControllerInfo[i].waitingForResponse = false;
        m_aControllerInfo[i].consecutiveTimeouts = 0;

        gpio_init(m_aControllerInfo[i].commPin);
        gpio_init(m_aControllerInfo[i].connectPin);

        gpio_set_dir(m_aControllerInfo[i].connectPin, GPIO_OUT);

        gpio_put(m_aControllerInfo[i].connectPin, true);

        //Initialize communication with the communication PIO
        gcn_comm_program_init(m_aControllerInfo[i].pio, //PIO
                              m_aControllerInfo[i].sm,  //State machine
                              m_aControllerInfo[i].offset, //Program offset
                              m_aControllerInfo[i].commPin, //Pin to read/write
                              250000); //Communication speed. 250KHz (4uS per bit)
        
        if(GetInterfaceType() == CONTROLLER_SIDE_INTERFACE)
            SwitchModeTX(&m_aControllerInfo[i]); //Controller side starts in TX to communicate with controllers
        else
            SwitchModeRX(&m_aControllerInfo[i]); //Console side starts in RX to recieve data from the console
    }

    m_nStaleCount++;
    m_bCanSleep = m_bSleepRequested = false;
    
    m_bStartupDone = false;
    m_StartupCount = 0;
    m_StartupTime = m_StartupPhaseTime = get_absolute_time();

    return true;
}

/*Write data out to the controller through the PIO
val: Max 32-bit value to be written out
len: Number of bits to actually shift out
*/
void ControllerComm::Write(ControllerCommInfo* pController, uint32_t* pVal, uint8_t len)
{
    uint8_t nWords = ((len - 1) / 32) + 1;
    uint8_t nOffset = ((nWords * 32) - len);
    uint32_t mask = 0xFFFFFFFF << (32 - nOffset);

    pio_sm_put_blocking(pController->pio, pController->sm, len); //Put the number of bits onto the FIFO
    //Shift out the data
    for(int16_t i = 0; i < nWords; i++)
        pio_sm_put_blocking(pController->pio, pController->sm, pVal[i]);
}

/*Read data from the controller through the PIO
pBuf: Buffer of words that the data is written into
pLen: Pointer number of bits read
*/
void ControllerComm::Read(ControllerCommInfo* pController, uint32_t* pBuf, uint8_t* pLen)
{
    uint8_t index = 0;
    uint8_t nWords;
    uint8_t nOffset;

    //Get the data from the PIO
    while(!pio_sm_is_rx_fifo_empty(pController->pio, pController->sm))
    {
        uint32_t v = (pio_sm_get_blocking(pController->pio, pController->sm));
        if(pio_sm_is_rx_fifo_empty(pController->pio, pController->sm)) //The last word is always the length
            *pLen = v;
        else
            pBuf[index++] = v; //All other words are the actual data
    }
    
    //Remove the stop bit
    pBuf[index - 1] <<= 1;
    //Decrement the length
    (*pLen)--;

    //Calculate the number of words the data would take
    nWords = (((*pLen) - 1) / 32) + 1;

    //Calculate the offset to shift the last word by
    nOffset = ((nWords * 32) - *pLen);
    if(nOffset)
        pBuf[index - 1] >>= nOffset;
}

void ControllerComm::StartupSequence()
{
    uint deltaStartupTime = absolute_time_diff_us(m_StartupTime, get_absolute_time());
    uint deltaPhaseTime = absolute_time_diff_us(m_StartupPhaseTime, get_absolute_time());
    //Check if the startup is done
    if(m_StartupCount >= 20)
    {
        //Turn off all the LEDs
        for(size_t i = 0; i < NUM_CONTROLLERS; i++)
            gpio_put(m_aControllerInfo[i].connectPin, false);

        printf("ControllerComm startup done\n");
        m_bStartupDone = true;
        return;
    }
    
    //Otherwise go through the LED sequence
    if(deltaPhaseTime > 100000)
    {
        gpio_put(m_aControllerInfo[m_StartupCount % NUM_CONTROLLERS].connectPin, false);
        m_StartupPhaseTime = get_absolute_time();
        m_StartupCount++;
    }
    else
        gpio_put(m_aControllerInfo[m_StartupCount % NUM_CONTROLLERS].connectPin, true);
}

void ControllerComm::MainBackground()
{
    bool bCanSleep = true;

    if(GetInterfaceType() == CONTROLLER_SIDE_INTERFACE)
        ControllerInterfaceBackground(m_bSleepRequested, &bCanSleep);
    else
        ConsoleInterfaceBackground(m_bSleepRequested, &bCanSleep);

    //Set the sleep flag
    if(m_bSleepRequested && bCanSleep)
        m_bCanSleep = true;
}
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

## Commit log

2024-03-02 Add parts to the controller interface
    [Controller Interface.kicad_sch]
2024-03-03 Fill out pin definitions. Start adding PIO
2024-03-16 Controller polling is done on a per controller timer
2024-03-17 Enable/disable driver to create open collector functionality. Add more communication interface logic
2024-03-24 Refactor rx/tx PIO into single program
    [Controller Interface.kicad_sch]
2024-03-31 Fix bug causing length to jump an extra bit occasionally
    [main.c]
2024-04-23 Rework to a CPP project
    [ControllerComm.cpp, WirelessComm.cpp, main.cpp]
2024-05-04 Semi-functioning wireless
2024-05-16 Optimize the RF library. Still 200uS missing
    [spi.cpp]
2024-05-16 Functioning wireless
2024-05-17 Successful wireless communication
2024-05-25 Fix bug for short messages
    [ControllerComm.cpp]
2024-06-08 Functional wireless control!
2024-06-08 Make wireless more good
2024-06-18 More power control stuff
2024-06-19 More work on the controller layout
    [Controller Interface.kicad_sch, controller_connectors.kicad_sch, power.kicad_sch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]
2024-07-09 Schematic updates
    [Controller Interface.kicad_pcb, Controller Interface.kicad_sch, controller_connectors.kicad_sch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]
2024-08-02 Completed schematic and layout
    [Controller Interface.kicad_pcb, controller_connectors.kicad_sch, power.kicad_sch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]
2024-08-05 Via too small
    [Controller Interface.kicad_pcb]
2024-08-05 Add stuff to console interface
    [Console Interface.kicad_sch, Controllers.kicad_sch, Power.kicad_sch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]
2024-08-16 Add plug STL
    [Controller Plug Clamp Bottom.stl, Controller Plug Clamp Top.stl]
2024-08-20 Switching regulator footprint doesn't exist
    [Controller Interface.kicad_pcb, power.kicad_sch]
2024-08-20 Create new footprint for plug clamp
    [Console Interface.kicad_pcb, Controllers.kicad_sch, Power.kicad_sch]
2024-09-10 Schematic/PCB fixes
    Fix VUSB supply. Add cut out for antenna wire.
    [Controller Interface.kicad_pcb, processor.kicad_sch]
2024-09-25 Changes for hardware
    Implement different pin numbers for different interface types. Add startup routine to controller comm.
2024-09-25 Use UART to debug
2024-11-23 Add console interface schematic
    [Console Interface.kicad_pcb, Console Interface.kicad_sch, Controllers.kicad_sch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]
2024-11-23 Fix missing ground
    [Console Interface.kicad_pcb]
2024-11-25 Fix another missing ground
    [Console Interface.kicad_pcb]
2025-04-17 Create a separate board for the LEDs
    [Controller Interface LB.kicad_pcb, Controller Interface LB.kicad_sch, Controller Interface.kicad_pcb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]
2025-07-09 Use separate board for lights
    [Console Interface.csv, Console Interface.kicad_pcb, Controller Interface LB.kicad_pcb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]
2026-08-13 Add CDC for serial printing
2026-08-13 Update KiCAD project
    [Controller Interface.kicad_sch, controller_connectors.kicad_sch, power.kicad_sch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]
2026-08-15 USB stuff
    Enable print statements earlier in code execution. Add supports for gamepad reporting.
